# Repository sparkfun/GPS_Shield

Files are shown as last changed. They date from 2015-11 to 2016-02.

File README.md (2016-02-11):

SparkFun GPS Logger Shield
====================

SparkFun GPS Shield (https://www.sparkfun.com/products/13750)

[*SparkFun GPS Shield (GPS-13750)*](https://www.sparkfun.com/products/13750)

The [SparkFun GPS Logger Shield](https://www.sparkfun.com/products/13750) equips your Arduino with access to a GPS module, µSD memory card socket, and all of the other peripherals you'll need to turn your Arduino into a position-tracking, speed-monitoring, altitude-observing wonder logger. The shield is based around a [GP3906-TLP GPS Module](https://cdn.sparkfun.com/assets/learn_tutorials/4/6/8/GP3906-TLP_DataSheet_Rev_A01.pdf) -- a 66-channel GPS receiver featuring a MediaTek MT3339 architecture and an up to 10Hz update rate.

Repository Contents
-------------------

* **/Documentation** - Data sheets, additional product information 
* **/Firmware** - Example code 
* **/Hardware** - All Eagle design files (.brd, .sch)
* **/Production** - Production panel files (.brd)

Documentation
--------------
* **[Hookup Guide](https://learn.sparkfun.com/tutorials/gps-logger-shield-hookup-guide)** - Basic hookup guide for the SparkFun GPS Logger Shield.

Product Versions
----------------
* [GPS-13750](https://www.sparkfun.com/products/13750)- Initial release of the GPS Logger Shield

Version History
---------------
* [V_1.6](https://github.com/sparkfun/GPS_Shield/releases/tag/V_1.6) - Original GPS Shield - older GPS module, no µSD card support.

License Information
-------------------

This product is _**open source**_! 

Please review the LICENSE.md file for license information. 

If you have any questions or concerns on licensing, please contact techsupport@sparkfun.com.

Distributed as-is; no warranty is given.

- Your friends at SparkFun.

_<COLLABORATION CREDIT>_

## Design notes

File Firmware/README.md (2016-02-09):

SparkFun GPS Logger Shield Firmware
===================================

* **Examples** - Arduino examples
    * Basic_Passthrough_Software - GPS NMEA string passthough from GPS module to the Arduino serial monitor. Uses software serial on pins 8/9 to communicate with the GPS module, leaving the hardware UART on pins 0/1 free for serial monitoring. Good for an Arduino Uno, Pro, and RedBoard.
	* Basic_Passthrough_Hardware - GPS NMEA string passthough from GPS module to the Arduino serial monitor. Uses a hardware serial UART on pins 0/1 to communicate with the GPS module. Good for an Arduino Leonardo or Zero.
	* TinyGPSPlus_GPS_Shield - Uses the [TinyGPS++ Arduino Library](https://github.com/mikalhart/TinyGPSPlus/releases) to parse NMEA strings, and prints position, speed, time, date, and other information to the serial monitor.
	* CSV_Logger_TinyGPSPlus - Logs pertinent GPS data to a &micro;SD card. Uses the [TinyGPS++ Arduino Library](https://github.com/mikalhart/TinyGPSPlus/releases) to parse NMEA strings, and Arduino's built-in SD library to create and write to files on an SD card.

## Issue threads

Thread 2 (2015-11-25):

v20 Issues

ericorosel, 2015-11-25:
-Need PROD_ID for batt. clip (according to the BOM it is CONN-08044)

-This may not be an issue at all, but when I match up the Redboard ISP header and the GPS Shield ISP header they seem to be slightly off.

that's it!

ericorosel, 2015-11-25:
sorry, that's BATT-08044

jimblom, 2015-11-30:
Battery's all taken care of.

The ISP header may actually be slightly off position on the Redboard. The GPS shield matches up with an Arduino Uno and a SAMD21 Dev Breakout. Either way, with a little give in the headers it's close enough.

ericorosel, 2015-11-30:
Sounds good, thanks!

Closed 2015-11-30.

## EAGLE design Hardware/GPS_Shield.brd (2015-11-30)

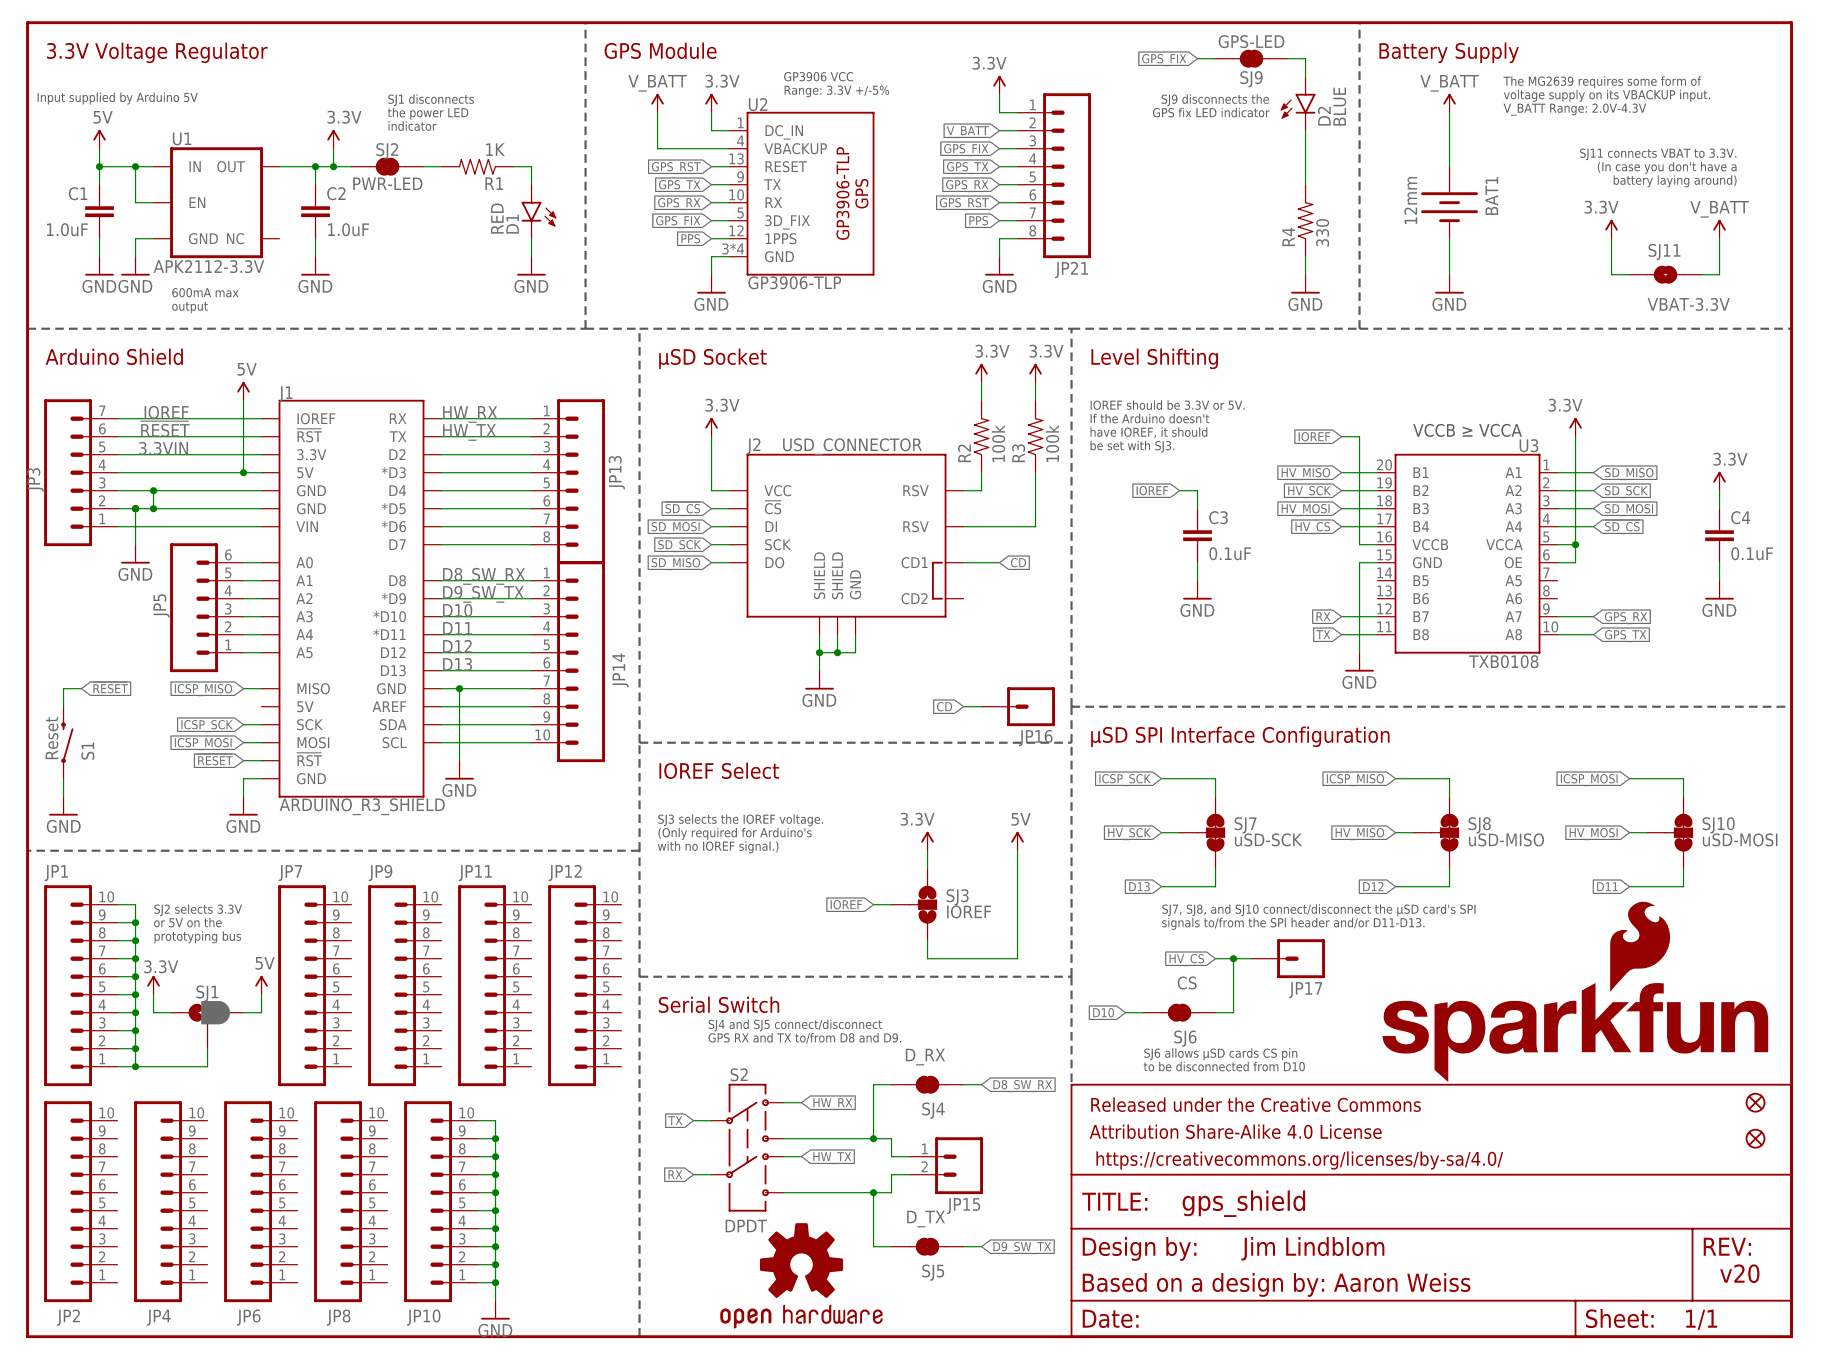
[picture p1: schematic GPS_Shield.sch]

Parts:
BAT1: 12mm; BATTCON_12MM
C1, C2: 1.0uF; 0603-CAP
C3, C4: 0.1uF; 0603-CAP
D1: RED; LED-0603
D2: BLUE; LED-0603
FRAME1: FRAME-LETTER; CREATIVE_COMMONS
J1: ARDUINO_R3_SHIELD; UNO_R3_SHIELD_ICSP_NOLABELS
J2: USD_CONNECTOR; MICRO-SD-SOCKET-PP
JP1, JP2, JP4, JP6, JP7, JP8, JP9, JP10, JP11, JP12, JP14: M10NO_SILK_PTH_FEMALE; 1X10_NO_SILK
JP3: M07NO_SILK; 1X07_NO_SILK
JP5: M06NO_SILK_FEMALE_PTH; 1X06_NO_SILK
JP13, JP21: M08NO_SILK_FEMALE_PTH; 1X08_NO_SILK
JP15: M021X02_NO_SILK; 1X02_NO_SILK
JP16, JP17: M01PTH_NO_SILK_YES_STOP; 1X01_NO_SILK
JP19, JP20: FIDUCIAL1X2; FIDUCIAL-1X2
LOGO1: OSHW-LOGOM; OSHW-LOGO-M
LOGO2: SFE_LOGO_NAME_FLAME.1_INCH; SFE_LOGO_NAME_FLAME_.1
R1: 1K; 0603-RES
R2, R3: 100k; 0603-RES
R4: 330; 0603-RES
S1: Reset; TACTILE-SWITCH-SMD
S2: DPDT; AYZ0202
SJ1: JUMPER-PAD-3-2OF3_NC_BY_PASTE; PAD-JUMPER-3-2OF3_NC_BY_PASTE_YES_SILK_FULL_BOX
SJ2: PWR-LED; PAD-JUMPER-2-NC_BY_TRACE_YES_SILK
SJ3: IOREF; PAD-JUMPER-3-NO_YES_SILK
SJ4: D_RX; PAD-JUMPER-2-NC_BY_TRACE_YES_SILK
SJ5: D_TX; PAD-JUMPER-2-NC_BY_TRACE_YES_SILK
SJ6: CS; PAD-JUMPER-2-NC_BY_TRACE_YES_SILK
SJ7: uSD-SCK; PAD-JUMPER-3-3OF3_NC_BY_TRACE_YES_SILK_FULL_BOX
SJ8: uSD-MISO; PAD-JUMPER-3-3OF3_NC_BY_TRACE_YES_SILK_FULL_BOX
SJ9: GPS-LED; PAD-JUMPER-2-NC_BY_TRACE_YES_SILK
SJ10: uSD-MOSI; PAD-JUMPER-3-3OF3_NC_BY_TRACE_YES_SILK_FULL_BOX
SJ11: VBAT-3.3V; PAD-JUMPER-2-NO_YES_SILK
U1: APK2112-3.3V; SOT23-5
U2: GP3906-TLP
U3: TXB0108; UFDFN-20

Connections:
3.3V: C2.1, C4.1, J2.VCC, JP21.1, R2.2, R3.2, SJ1.1, SJ2.1, SJ3.1, SJ11.1, U1.5 (OUT), U2.1 (DC_IN), U3.5 (VCCA), U3.6 (OE)
3.3VIN: J1.3.3V, JP3.5
5V: C1.1, J1.5V, JP3.4, SJ1.3, SJ3.3, U1.1 (IN), U1.3 (EN)
!RESET!: J1.RES (!RST!), J1.RST_ICSP (!RST!), JP3.6, S1.3 (2)
!SD_CS!: J2.CS (!CS), U3.4 (A4)
CD: J2.CD1, JP16.1
D8_SW_RX: J1.D8, JP14.1, SJ4.1
D9_SW_TX: J1.D9 (*D9), JP14.2, SJ5.1
D10: J1.D10 (*D10), JP14.3, SJ6.2
D11: J1.D11 (*D11), JP14.4, SJ10.3
D12: J1.D12, JP14.5, SJ8.3
D13: J1.D13, JP14.6, SJ7.3
GND: BAT1.GND (-), C1.2, C2.2, C3.2, C4.2, D1.C, J1.GND@0 (GND), J1.GND@1 (GND), J1.GND@2 (GND), J1.GND_ICSP (GND), J2.GND, J2.GND1 (SHIELD), J2.GND3 (SHIELD), JP3.2, JP3.3, JP10.1, JP10.2, JP10.3, JP10.4, JP10.5, JP10.6, JP10.7, JP10.8, JP10.9, JP10.10, JP14.7, JP21.8, R4.1, S1.1, U1.2 (GND), U2.3 (GND), U2.8 (GND), U2.11 (GND), U2.20 (GND), U3.15 (GND)
GPS_FIX: JP21.3, SJ9.2, U2.5 (3D_FIX)
GPS_RST: JP21.6, U2.13 (RESET)
GPS_RX: JP21.5, U2.10 (RX), U3.9 (A7)
GPS_TX: JP21.4, U2.9 (TX), U3.10 (A8)
HV_CS: JP17.1, SJ6.1, U3.17 (B4)
HV_MISO: SJ8.2, U3.20 (B1)
HV_MOSI: SJ10.2, U3.18 (B3)
HV_SCK: SJ7.2, U3.19 (B2)
HW_RX: J1.RX, JP13.1, S2.1
HW_TX: J1.TX, JP13.2, S2.4
ICSP_MISO: J1.MISO, SJ8.1
ICSP_MOSI: J1.MOSI, SJ10.1
ICSP_SCK: J1.SCK, SJ7.1
IOREF: C3.1, J1.IOREF, JP3.7, SJ3.2, U3.16 (VCCB)
unnamed: D1.A, R1.1
unnamed: D2.C, R4.2
unnamed: J1.A5, JP5.1
unnamed: J1.A4, JP5.2
unnamed: J1.D2, JP13.3
unnamed: J1.D3 (*D3), JP13.4
unnamed: J1.D4, JP13.5
unnamed: J1.D5 (*D5), JP13.6
unnamed: J1.D6 (*D6), JP13.7
unnamed: J1.D7, JP13.8
unnamed: J1.A3, JP5.3
unnamed: J1.A2, JP5.4
unnamed: J1.A1, JP5.5
unnamed: J1.A0, JP5.6
unnamed: R1.2, SJ2.2
unnamed: JP1.1, JP1.2, JP1.3, JP1.4, JP1.5, JP1.6, JP1.7, JP1.8, JP1.9, JP1.10, SJ1.2
unnamed: D2.A, SJ9.1
unnamed: J2.RSV1 (RSV), R2.1
unnamed: J2.RSV2 (RSV), R3.1
unnamed: J1.AREF, JP14.8
unnamed: J1.SDA, JP14.9
unnamed: J1.SCL, JP14.10
unnamed: J1.VIN, JP3.1
unnamed: JP15.2, S2.6, SJ5.2
unnamed: JP15.1, S2.3, SJ4.2
PPS: JP21.7, U2.12 (1PPS)
RX: S2.5, U3.12 (B7)
SD_MISO: J2.DO, U3.1 (A1)
SD_MOSI: J2.DI, U3.3 (A3)
SD_SCK: J2.SCLK (SCK), U3.2 (A2)
TX: S2.2, U3.11 (B8)
V_BATT: BAT1.PWR@1 (+), JP21.2, SJ11.2, U2.4 (VBACKUP)

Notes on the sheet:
GPS Module
Arduino Shield
Serial Switch
Jim Lindblom
v20
Based on a design by: Aaron Weiss
µSD Socket
Level Shifting
3.3V Voltage Regulator
µSD SPI Interface Configuration
IOREF Select
Input supplied by Arduino 5V
600mA max output
SJ1 disconnects the power LED indicator
SJ9 disconnects the GPS fix LED indicator
SJ2 selects 3.3V or 5V on the prototyping bus
VCCB ≥ VCCA
IOREF should be 3.3V or 5V. If the Arduino doesn't have IOREF, it should be set with SJ3.
SJ3 selects the IOREF voltage. (Only required for Arduino's with no IOREF signal.)
SJ7, SJ8, and SJ10 connect/disconnect the µSD card's SPI signals to/from the SPI header and/or D11-D13.
SJ6 allows µSD cards CS pin to be disconnected from D10
SJ4 and SJ5 connect/disconnect GPS RX and TX to/from D8 and D9.
GP3906 VCC Range: 3.3V +/-5%
SJ11 connects VBAT to 3.3V. (In case you don't have a battery laying around)
Battery Supply
The MG2639 requires some form of voltage supply on its VBACKUP input. V_BATT Range: 2.0V-4.3V

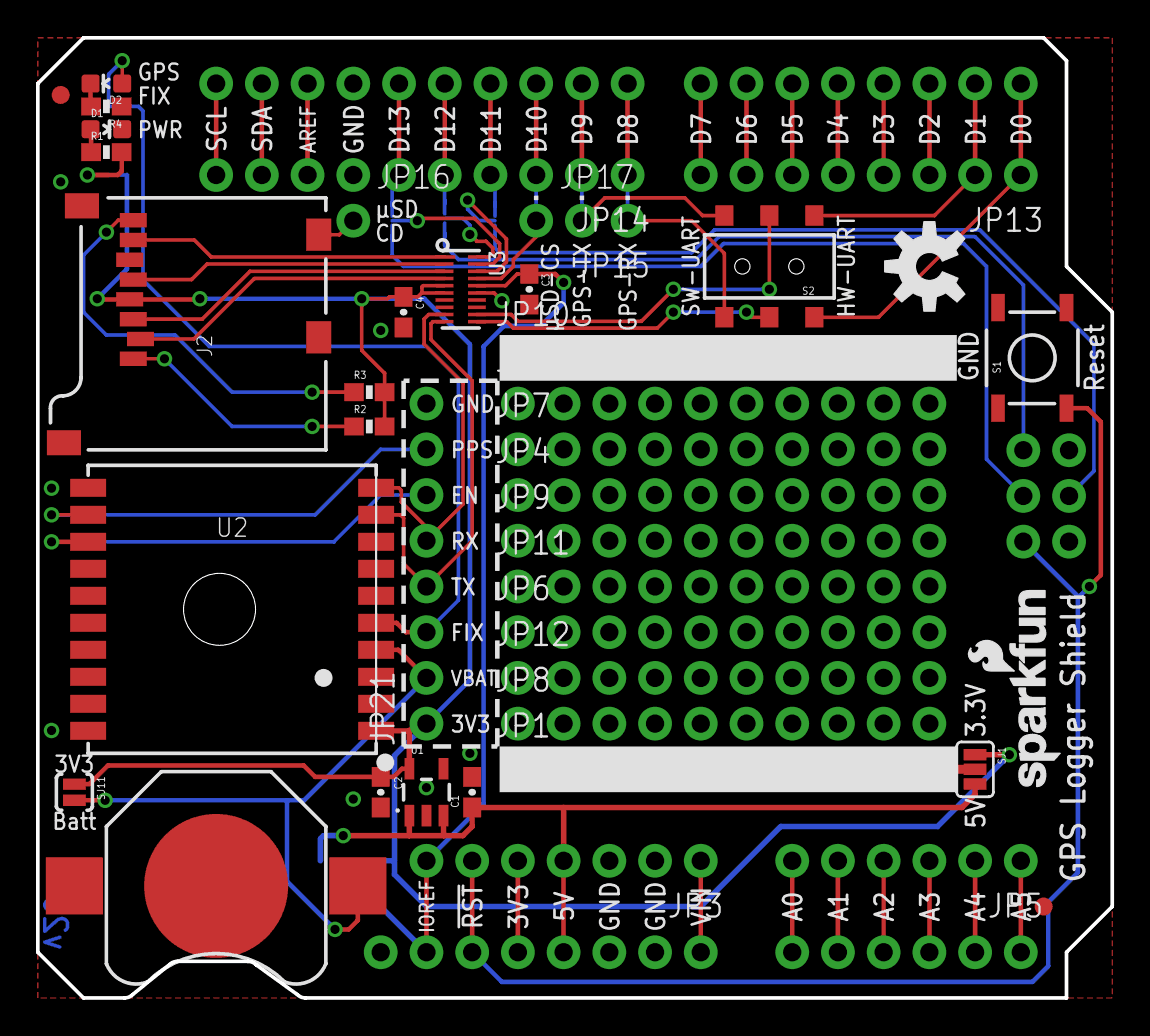
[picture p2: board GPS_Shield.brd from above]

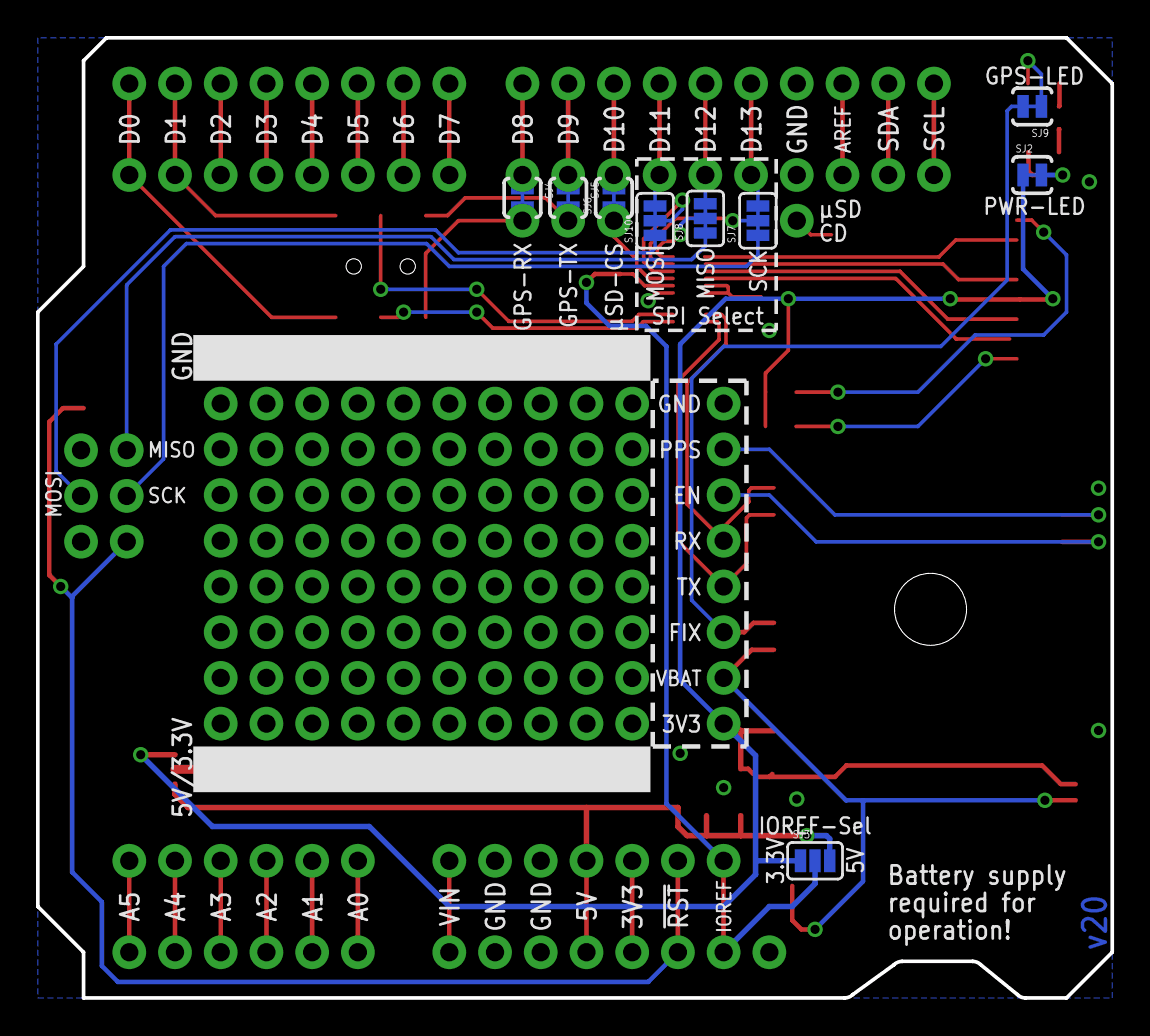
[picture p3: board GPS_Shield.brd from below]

Board: 2 copper layers, 59.7 x 53.3 mm, 52 parts (9 on the bottom side), 59 nets.

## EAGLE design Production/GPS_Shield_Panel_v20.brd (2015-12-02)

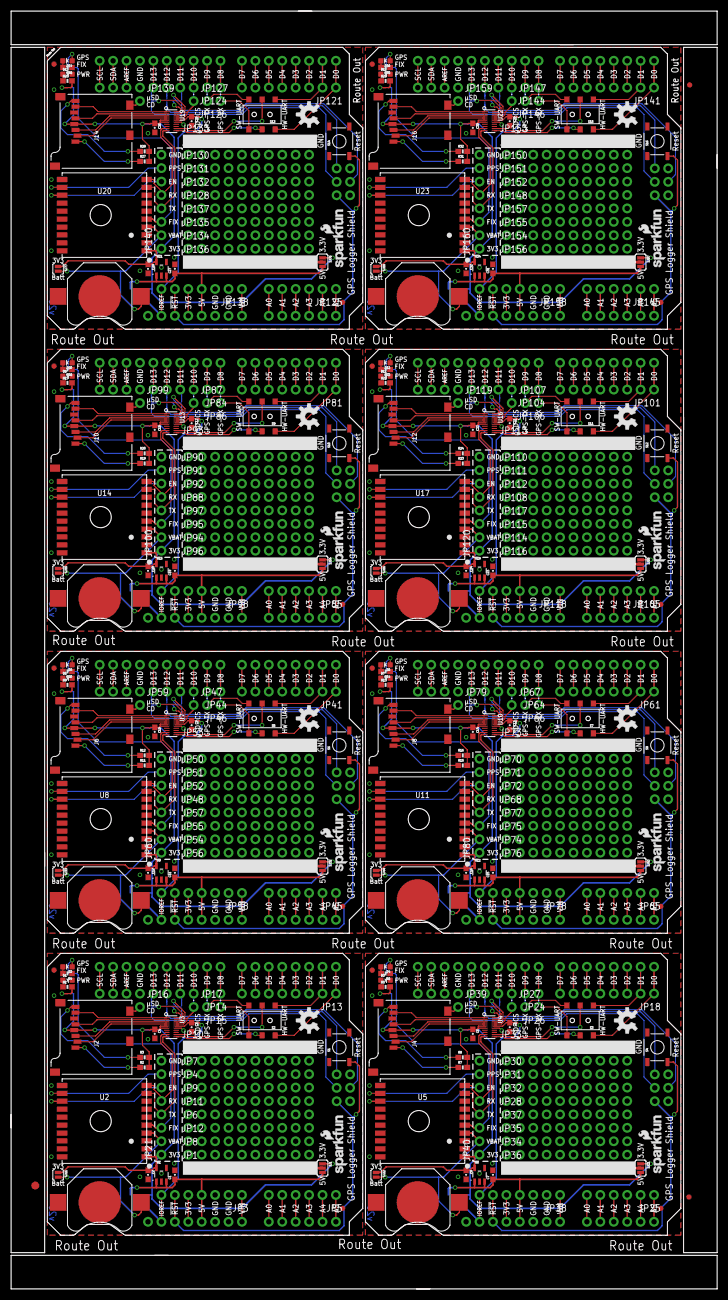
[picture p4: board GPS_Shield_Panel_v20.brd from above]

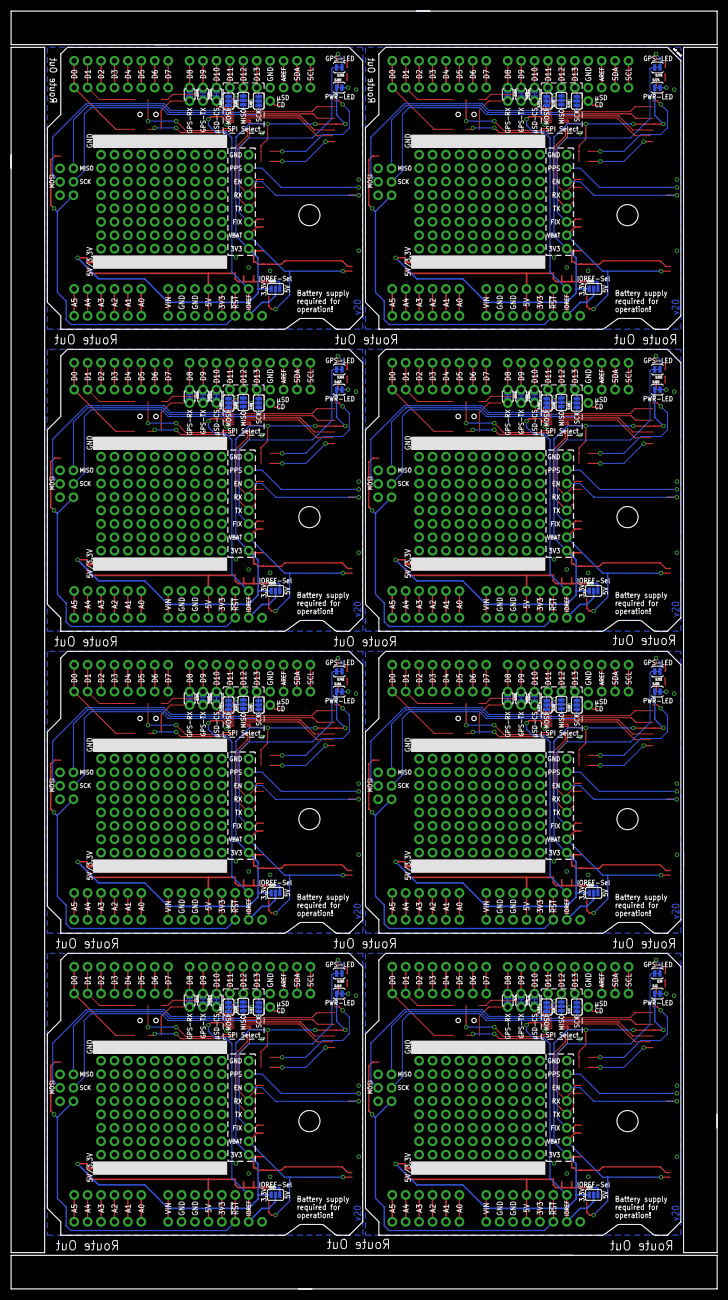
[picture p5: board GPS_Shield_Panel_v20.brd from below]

Board: 2 copper layers, 133.6 x 241.8 mm, 411 parts (72 on the bottom side), 472 nets.

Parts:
BAT1, BAT2, BAT3, BAT4, BAT5, BAT6, BAT7, BAT8: 12mm; BATTCON_12MM
C1, C2, C7, C8, C11, C12, C15, C16, C19, C20, C23, C24, C27, C28, C31, C32: 1.0uF; 0603-CAP
C3, C4, C5, C6, C9, C10, C13, C14, C17, C18, C21, C22, C25, C26, C29, C30: 0.1uF; 0603-CAP
D1, D3, D5, D7, D9, D11, D13, D15: RED; LED-0603
D2, D4, D6, D8, D10, D12, D14, D16: BLUE; LED-0603
E$1: FIDUCIAL-1.5X3
E$4, E$5: FIDUCIAL-1X2
J1, J3, J5, J7, J9, J11, J13, J15: ARDUINO_R3_SHIELD; UNO_R3_SHIELD_ICSP_NOLABELS
J2, J4, J6, J8, J10, J12, J14, J16: USD_CONNECTOR; MICRO-SD-SOCKET-PP
JP1, JP2, JP4, JP6, JP7, JP8, JP9, JP10, JP11, JP12, JP14, JP24, JP28, JP29, JP30, JP31, JP32, JP33, JP34, JP35, JP36, JP37, JP44, JP48, JP49, JP50, JP51, JP52, JP53, JP54, JP55, JP56, JP57, JP64, JP68, JP69, JP70, JP71, JP72, JP73, JP74, JP75, JP76, JP77, JP84, JP88, JP89, JP90, JP91, JP92, JP93, JP94, JP95, JP96, JP97, JP104, JP108, JP109, JP110, JP111, JP112, JP113, JP114, JP115, JP116, JP117, JP124, JP128, JP129, JP130, JP131, JP132, JP133, JP134, JP135, JP136, JP137, JP144, JP148, JP149, JP150, JP151, JP152, JP153, JP154, JP155, JP156, JP157: 1X10_NO_SILK
JP3, JP38, JP58, JP78, JP98, JP118, JP138, JP158: 1X07_NO_SILK
JP5, JP25, JP45, JP65, JP85, JP105, JP125, JP145: 1X06_NO_SILK
JP13, JP18, JP21, JP40, JP41, JP60, JP61, JP80, JP81, JP100, JP101, JP120, JP121, JP140, JP141, JP160: 1X08_NO_SILK
JP15, JP26, JP46, JP66, JP86, JP106, JP126, JP146: 1X02_NO_SILK
JP16, JP17, JP27, JP39, JP47, JP59, JP67, JP79, JP87, JP99, JP107, JP119, JP127, JP139, JP147, JP159: 1X01_NO_SILK
JP19, JP20, JP22, JP23, JP42, JP43, JP62, JP63, JP82, JP83, JP102, JP103, JP122, JP123, JP142, JP143: FIDUCIAL1X2; FIDUCIAL-1X2
LOGO1, LOGO4, LOGO6, LOGO8, LOGO10, LOGO12, LOGO14, LOGO16: OSHW-LOGOM; OSHW-LOGO-M
LOGO2, LOGO3, LOGO5, LOGO7, LOGO9, LOGO11, LOGO13, LOGO15: SFE_LOGO_NAME_FLAME.1_INCH; SFE_LOGO_NAME_FLAME_.1
R1, R5, R9, R13, R17, R21, R25, R29: 1K; 0603-RES
R2, R3, R7, R8, R11, R12, R15, R16, R19, R20, R23, R24, R27, R28, R31, R32: 100k; 0603-RES
R4, R6, R10, R14, R18, R22, R26, R30: 330; 0603-RES
S1, S4, S6, S8, S10, S12, S14, S16: Reset; TACTILE-SWITCH-SMD
S2, S3, S5, S7, S9, S11, S13, S15: DPDT; AYZ0202
SJ1, SJ21, SJ32, SJ43, SJ54, SJ65, SJ76, SJ87: PAD-JUMPER-3-2OF3_NC_BY_PASTE_YES_SILK_FULL_BOX
SJ2, SJ19, SJ30, SJ41, SJ52, SJ63, SJ74, SJ85: PWR-LED; PAD-JUMPER-2-NC_BY_TRACE_YES_SILK
SJ3, SJ14, SJ25, SJ36, SJ47, SJ58, SJ69, SJ80: IOREF; PAD-JUMPER-3-NO_YES_SILK
SJ4, SJ12, SJ23, SJ34, SJ45, SJ56, SJ67, SJ78: D_RX; PAD-JUMPER-2-NC_BY_TRACE_YES_SILK
SJ5, SJ13, SJ24, SJ35, SJ46, SJ57, SJ68, SJ79: D_TX; PAD-JUMPER-2-NC_BY_TRACE_YES_SILK
SJ6, SJ18, SJ29, SJ40, SJ51, SJ62, SJ73, SJ84: CS; PAD-JUMPER-2-NC_BY_TRACE_YES_SILK
SJ7, SJ17, SJ28, SJ39, SJ50, SJ61, SJ72, SJ83: uSD-SCK; PAD-JUMPER-3-3OF3_NC_BY_TRACE_YES_SILK_FULL_BOX
SJ8, SJ15, SJ26, SJ37, SJ48, SJ59, SJ70, SJ81: uSD-MISO; PAD-JUMPER-3-3OF3_NC_BY_TRACE_YES_SILK_FULL_BOX
SJ9, SJ20, SJ31, SJ42, SJ53, SJ64, SJ75, SJ86: GPS-LED; PAD-JUMPER-2-NC_BY_TRACE_YES_SILK
SJ10, SJ16, SJ27, SJ38, SJ49, SJ60, SJ71, SJ82: uSD-MOSI; PAD-JUMPER-3-3OF3_NC_BY_TRACE_YES_SILK_FULL_BOX
SJ11, SJ22, SJ33, SJ44, SJ55, SJ66, SJ77, SJ88: VBAT-3.3V; PAD-JUMPER-2-NO_YES_SILK
U1, U6, U9, U12, U15, U18, U21, U24: APK2112-3.3V; SOT23-5
U2, U5, U8, U11, U14, U17, U20, U23: GP3906-TLP
U3, U4, U7, U10, U13, U16, U19, U22: TXB0108; UFDFN-20

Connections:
3.3V: C2.1, C4.1, J2.VCC, JP21.1, R2.2, R3.2, SJ1.1, SJ2.1, SJ3.1, SJ11.1, U1.5, U2.1, U3.5, U3.6
3.3V1: C6.1, C8.1, J4.VCC, JP40.1, R7.2, R8.2, SJ14.1, SJ19.1, SJ21.1, SJ22.1, U4.5, U4.6, U5.1, U6.5
3.3V2: C10.1, C12.1, J6.VCC, JP60.1, R11.2, R12.2, SJ25.1, SJ30.1, SJ32.1, SJ33.1, U7.5, U7.6, U8.1, U9.5
3.3V3: C14.1, C16.1, J8.VCC, JP80.1, R15.2, R16.2, SJ36.1, SJ41.1, SJ43.1, SJ44.1, U10.5, U10.6, U11.1, U12.5
3.3V4: C18.1, C20.1, J10.VCC, JP100.1, R19.2, R20.2, SJ47.1, SJ52.1, SJ54.1, SJ55.1, U13.5, U13.6, U14.1, U15.5
3.3V5: C22.1, C24.1, J12.VCC, JP120.1, R23.2, R24.2, SJ58.1, SJ63.1, SJ65.1, SJ66.1, U16.5, U16.6, U17.1, U18.5
3.3V6: C26.1, C28.1, J14.VCC, JP140.1, R27.2, R28.2, SJ69.1, SJ74.1, SJ76.1, SJ77.1, U19.5, U19.6, U20.1, U21.5
3.3V7: C30.1, C32.1, J16.VCC, JP160.1, R31.2, R32.2, SJ80.1, SJ85.1, SJ87.1, SJ88.1, U22.5, U22.6, U23.1, U24.5
3.3VIN: J1.3.3V, JP3.5
3.3VIN1: J3.3.3V, JP38.5
3.3VIN2: J5.3.3V, JP58.5
3.3VIN3: J7.3.3V, JP78.5
3.3VIN4: J9.3.3V, JP98.5
3.3VIN5: J11.3.3V, JP118.5
3.3VIN6: J13.3.3V, JP138.5
3.3VIN7: J15.3.3V, JP158.5
5V: C1.1, J1.5V, JP3.4, SJ1.3, SJ3.3, U1.1, U1.3
5V1: C7.1, J3.5V, JP38.4, SJ14.3, SJ21.3, U6.1, U6.3
5V2: C11.1, J5.5V, JP58.4, SJ25.3, SJ32.3, U9.1, U9.3
5V3: C15.1, J7.5V, JP78.4, SJ36.3, SJ43.3, U12.1, U12.3
5V4: C19.1, J9.5V, JP98.4, SJ47.3, SJ54.3, U15.1, U15.3
5V5: C23.1, J11.5V, JP118.4, SJ58.3, SJ65.3, U18.1, U18.3
5V6: C27.1, J13.5V, JP138.4, SJ69.3, SJ76.3, U21.1, U21.3
5V7: C31.1, J15.5V, JP158.4, SJ80.3, SJ87.3, U24.1, U24.3
!RESET!: J1.RES, J1.RST_ICSP, JP3.6, S1.3
!RESET!1: J3.RES, J3.RST_ICSP, JP38.6, S4.3
!RESET!2: J5.RES, J5.RST_ICSP, JP58.6, S6.3
!RESET!3: J7.RES, J7.RST_ICSP, JP78.6, S8.3
!RESET!4: J9.RES, J9.RST_ICSP, JP98.6, S10.3
!RESET!5: J11.RES, J11.RST_ICSP, JP118.6, S12.3
!RESET!6: J13.RES, J13.RST_ICSP, JP138.6, S14.3
!RESET!7: J15.RES, J15.RST_ICSP, JP158.6, S16.3
!SD_CS!: J2.CS, U3.4
!SD_CS!1: J4.CS, U4.4
!SD_CS!2: J6.CS, U7.4
!SD_CS!3: J8.CS, U10.4
!SD_CS!4: J10.CS, U13.4
!SD_CS!5: J12.CS, U16.4
!SD_CS!6: J14.CS, U19.4
!SD_CS!7: J16.CS, U22.4
CD: J2.CD1, JP16.1
CD1: J4.CD1, JP39.1
CD2: J6.CD1, JP59.1
CD3: J8.CD1, JP79.1
CD4: J10.CD1, JP99.1
CD5: J12.CD1, JP119.1
CD6: J14.CD1, JP139.1
CD7: J16.CD1, JP159.1
D1: J3.D10, JP24.3, SJ18.2
D2: J3.D11, JP24.4, SJ16.3
D3: J3.D12, JP24.5, SJ15.3
D4: J3.D13, JP24.6, SJ17.3
D5: J5.D10, JP44.3, SJ29.2
D6: J5.D11, JP44.4, SJ27.3
D7: J5.D12, JP44.5, SJ26.3
D8: J5.D13, JP44.6, SJ28.3
D8_SW_RX: J1.D8, JP14.1, SJ4.1
D8_SW_RX1: J3.D8, JP24.1, SJ12.1
D8_SW_RX2: J5.D8, JP44.1, SJ23.1
D8_SW_RX3: J7.D8, JP64.1, SJ34.1
D8_SW_RX4: J9.D8, JP84.1, SJ45.1
D8_SW_RX5: J11.D8, JP104.1, SJ56.1
D8_SW_RX6: J13.D8, JP124.1, SJ67.1
D8_SW_RX7: J15.D8, JP144.1, SJ78.1
D9: J7.D10, JP64.3, SJ40.2
D9_SW_TX: J1.D9, JP14.2, SJ5.1
D9_SW_TX1: J3.D9, JP24.2, SJ13.1
D9_SW_TX2: J5.D9, JP44.2, SJ24.1
D9_SW_TX3: J7.D9, JP64.2, SJ35.1
D9_SW_TX4: J9.D9, JP84.2, SJ46.1
D9_SW_TX5: J11.D9, JP104.2, SJ57.1
D9_SW_TX6: J13.D9, JP124.2, SJ68.1
D9_SW_TX7: J15.D9, JP144.2, SJ79.1
D10: J1.D10, JP14.3, SJ6.2
D11: J1.D11, JP14.4, SJ10.3
D12: J1.D12, JP14.5, SJ8.3
D13: J1.D13, JP14.6, SJ7.3
D14: J7.D11, JP64.4, SJ38.3
D15: J7.D12, JP64.5, SJ37.3
D16: J7.D13, JP64.6, SJ39.3
D17: J9.D10, JP84.3, SJ51.2
D18: J9.D11, JP84.4, SJ49.3
D19: J9.D12, JP84.5, SJ48.3
D20: J9.D13, JP84.6, SJ50.3
D21: J11.D10, JP104.3, SJ62.2
D22: J11.D11, JP104.4, SJ60.3
D23: J11.D12, JP104.5, SJ59.3
D24: J11.D13, JP104.6, SJ61.3
D25: J13.D10, JP124.3, SJ73.2
D26: J13.D11, JP124.4, SJ71.3
D27: J13.D12, JP124.5, SJ70.3
D28: J13.D13, JP124.6, SJ72.3
D29: J15.D10, JP144.3, SJ84.2
D30: J15.D11, JP144.4, SJ82.3
D31: J15.D12, JP144.5, SJ81.3
D32: J15.D13, JP144.6, SJ83.3
GND: BAT1.GND, C1.2, C2.2, C3.2, C4.2, D1.C, J1.GND@0, J1.GND@1, J1.GND@2, J1.GND_ICSP, J2.GND, J2.GND1, J2.GND3, JP3.2, JP3.3, JP10.1, JP10.2, JP10.3, JP10.4, JP10.5, JP10.6, JP10.7, JP10.8, JP10.9, JP10.10, JP14.7, JP21.8, R4.1, S1.1, U1.2, U2.3, U2.8, U2.11, U2.20, U3.15
GND1: BAT2.GND, C5.2, C6.2, C7.2, C8.2, D3.C, J3.GND@0, J3.GND@1, J3.GND@2, J3.GND_ICSP, J4.GND, J4.GND1, J4.GND3, JP24.7, JP33.1, JP33.2, JP33.3, JP33.4, JP33.5, JP33.6, JP33.7, JP33.8, JP33.9, JP33.10, JP38.2, JP38.3, JP40.8, R6.1, S4.1, U4.15, U5.3, U5.8, U5.11, U5.20, U6.2
GND2: BAT3.GND, C9.2, C10.2, C11.2, C12.2, D5.C, J5.GND@0, J5.GND@1, J5.GND@2, J5.GND_ICSP, J6.GND, J6.GND1, J6.GND3, JP44.7, JP53.1, JP53.2, JP53.3, JP53.4, JP53.5, JP53.6, JP53.7, JP53.8, JP53.9, JP53.10, JP58.2, JP58.3, JP60.8, R10.1, S6.1, U7.15, U8.3, U8.8, U8.11, U8.20, U9.2
GND3: BAT4.GND, C13.2, C14.2, C15.2, C16.2, D7.C, J7.GND@0, J7.GND@1, J7.GND@2, J7.GND_ICSP, J8.GND, J8.GND1, J8.GND3, JP64.7, JP73.1, JP73.2, JP73.3, JP73.4, JP73.5, JP73.6, JP73.7, JP73.8, JP73.9, JP73.10, JP78.2, JP78.3, JP80.8, R14.1, S8.1, U10.15, U11.3, U11.8, U11.11, U11.20, U12.2
GND4: BAT5.GND, C17.2, C18.2, C19.2, C20.2, D9.C, J9.GND@0, J9.GND@1, J9.GND@2, J9.GND_ICSP, J10.GND, J10.GND1, J10.GND3, JP84.7, JP93.1, JP93.2, JP93.3, JP93.4, JP93.5, JP93.6, JP93.7, JP93.8, JP93.9, JP93.10, JP98.2, JP98.3, JP100.8, R18.1, S10.1, U13.15, U14.3, U14.8, U14.11, U14.20, U15.2
GND5: BAT6.GND, C21.2, C22.2, C23.2, C24.2, D11.C, J11.GND@0, J11.GND@1, J11.GND@2, J11.GND_ICSP, J12.GND, J12.GND1, J12.GND3, JP104.7, JP113.1, JP113.2, JP113.3, JP113.4, JP113.5, JP113.6, JP113.7, JP113.8, JP113.9, JP113.10, JP118.2, JP118.3, JP120.8, R22.1, S12.1, U16.15, U17.3, U17.8, U17.11, U17.20, U18.2
GND6: BAT7.GND, C25.2, C26.2, C27.2, C28.2, D13.C, J13.GND@0, J13.GND@1, J13.GND@2, J13.GND_ICSP, J14.GND, J14.GND1, J14.GND3, JP124.7, JP133.1, JP133.2, JP133.3, JP133.4, JP133.5, JP133.6, JP133.7, JP133.8, JP133.9, JP133.10, JP138.2, JP138.3, JP140.8, R26.1, S14.1, U19.15, U20.3, U20.8, U20.11, U20.20, U21.2
GND7: BAT8.GND, C29.2, C30.2, C31.2, C32.2, D15.C, J15.GND@0, J15.GND@1, J15.GND@2, J15.GND_ICSP, J16.GND, J16.GND1, J16.GND3, JP144.7, JP153.1, JP153.2, JP153.3, JP153.4, JP153.5, JP153.6, JP153.7, JP153.8, JP153.9, JP153.10, JP158.2, JP158.3, JP160.8, R30.1, S16.1, U22.15, U23.3, U23.8, U23.11, U23.20, U24.2
GPS_FIX: JP21.3, SJ9.2, U2.5
GPS_FIX1: JP40.3, SJ20.2, U5.5
GPS_FIX2: JP60.3, SJ31.2, U8.5
GPS_FIX3: JP80.3, SJ42.2, U11.5
GPS_FIX4: JP100.3, SJ53.2, U14.5
GPS_FIX5: JP120.3, SJ64.2, U17.5
GPS_FIX6: JP140.3, SJ75.2, U20.5
GPS_FIX7: JP160.3, SJ86.2, U23.5
GPS_RST: JP21.6, U2.13
GPS_RST1: JP40.6, U5.13
GPS_RST2: JP60.6, U8.13
GPS_RST3: JP80.6, U11.13
GPS_RST4: JP100.6, U14.13
GPS_RST5: JP120.6, U17.13
GPS_RST6: JP140.6, U20.13
GPS_RST7: JP160.6, U23.13
GPS_RX: JP21.5, U2.10, U3.9
GPS_RX1: JP40.5, U4.9, U5.10
GPS_RX2: JP60.5, U7.9, U8.10
GPS_RX3: JP80.5, U10.9, U11.10
GPS_RX4: JP100.5, U13.9, U14.10
GPS_RX5: JP120.5, U16.9, U17.10
GPS_RX6: JP140.5, U19.9, U20.10
GPS_RX7: JP160.5, U22.9, U23.10
GPS_TX: JP21.4, U2.9, U3.10
GPS_TX1: JP40.4, U4.10, U5.9
GPS_TX2: JP60.4, U7.10, U8.9
GPS_TX3: JP80.4, U10.10, U11.9
GPS_TX4: JP100.4, U13.10, U14.9
GPS_TX5: JP120.4, U16.10, U17.9
GPS_TX6: JP140.4, U19.10, U20.9
GPS_TX7: JP160.4, U22.10, U23.9
HV_CS: JP17.1, SJ6.1, U3.17
HV_CS1: JP27.1, SJ18.1, U4.17
HV_CS2: JP47.1, SJ29.1, U7.17
HV_CS3: JP67.1, SJ40.1, U10.17
HV_CS4: JP87.1, SJ51.1, U13.17
HV_CS5: JP107.1, SJ62.1, U16.17
HV_CS6: JP127.1, SJ73.1, U19.17
HV_CS7: JP147.1, SJ84.1, U22.17
HV_MISO: SJ8.2, U3.20
HV_MISO1: SJ15.2, U4.20
HV_MISO2: SJ26.2, U7.20
HV_MISO3: SJ37.2, U10.20
HV_MISO4: SJ48.2, U13.20
HV_MISO5: SJ59.2, U16.20
HV_MISO6: SJ70.2, U19.20
HV_MISO7: SJ81.2, U22.20
HV_MOSI: SJ10.2, U3.18
HV_MOSI1: SJ16.2, U4.18
HV_MOSI2: SJ27.2, U7.18
HV_MOSI3: SJ38.2, U10.18
HV_MOSI4: SJ49.2, U13.18
HV_MOSI5: SJ60.2, U16.18
HV_MOSI6: SJ71.2, U19.18
HV_MOSI7: SJ82.2, U22.18
HV_SCK: SJ7.2, U3.19
HV_SCK1: SJ17.2, U4.19
HV_SCK2: SJ28.2, U7.19
HV_SCK3: SJ39.2, U10.19
HV_SCK4: SJ50.2, U13.19
HV_SCK5: SJ61.2, U16.19
HV_SCK6: SJ72.2, U19.19
HV_SCK7: SJ83.2, U22.19
HW_RX: J1.RX, JP13.1, S2.1
HW_RX1: J3.RX, JP18.1, S3.1
HW_RX2: J5.RX, JP41.1, S5.1
HW_RX3: J7.RX, JP61.1, S7.1
HW_RX4: J9.RX, JP81.1, S9.1
HW_RX5: J11.RX, JP101.1, S11.1
HW_RX6: J13.RX, JP121.1, S13.1
HW_RX7: J15.RX, JP141.1, S15.1
HW_TX: J1.TX, JP13.2, S2.4
HW_TX1: J3.TX, JP18.2, S3.4
HW_TX2: J5.TX, JP41.2, S5.4
HW_TX3: J7.TX, JP61.2, S7.4
HW_TX4: J9.TX, JP81.2, S9.4
HW_TX5: J11.TX, JP101.2, S11.4
HW_TX6: J13.TX, JP121.2, S13.4
HW_TX7: J15.TX, JP141.2, S15.4
ICSP_MISO: J1.MISO, SJ8.1
ICSP_MISO1: J3.MISO, SJ15.1
ICSP_MISO2: J5.MISO, SJ26.1
ICSP_MISO3: J7.MISO, SJ37.1
ICSP_MISO4: J9.MISO, SJ48.1
ICSP_MISO5: J11.MISO, SJ59.1
ICSP_MISO6: J13.MISO, SJ70.1
ICSP_MISO7: J15.MISO, SJ81.1
ICSP_MOSI: J1.MOSI, SJ10.1
ICSP_MOSI1: J3.MOSI, SJ16.1
ICSP_MOSI2: J5.MOSI, SJ27.1
ICSP_MOSI3: J7.MOSI, SJ38.1
ICSP_MOSI4: J9.MOSI, SJ49.1
ICSP_MOSI5: J11.MOSI, SJ60.1
ICSP_MOSI6: J13.MOSI, SJ71.1
ICSP_MOSI7: J15.MOSI, SJ82.1
ICSP_SCK: J1.SCK, SJ7.1
ICSP_SCK1: J3.SCK, SJ17.1
ICSP_SCK2: J5.SCK, SJ28.1
ICSP_SCK3: J7.SCK, SJ39.1
ICSP_SCK4: J9.SCK, SJ50.1
ICSP_SCK5: J11.SCK, SJ61.1
ICSP_SCK6: J13.SCK, SJ72.1
ICSP_SCK7: J15.SCK, SJ83.1
IOREF: C3.1, J1.IOREF, JP3.7, SJ3.2, U3.16
IOREF1: C5.1, J3.IOREF, JP38.7, SJ14.2, U4.16
IOREF2: C9.1, J5.IOREF, JP58.7, SJ25.2, U7.16
IOREF3: C13.1, J7.IOREF, JP78.7, SJ36.2, U10.16
IOREF4: C17.1, J9.IOREF, JP98.7, SJ47.2, U13.16
IOREF5: C21.1, J11.IOREF, JP118.7, SJ58.2, U16.16
IOREF6: C25.1, J13.IOREF, JP138.7, SJ69.2, U19.16
IOREF7: C29.1, J15.IOREF, JP158.7, SJ80.2, U22.16
unnamed: D1.A, R1.1
unnamed: D2.C, R4.2
unnamed: J1.A5, JP5.1
unnamed: J1.A4, JP5.2
unnamed: J1.D2, JP13.3
unnamed: J1.D3, JP13.4
unnamed: J1.D4, JP13.5
unnamed: J1.D5, JP13.6
unnamed: J1.D6, JP13.7
unnamed: J1.D7, JP13.8
unnamed: J1.A3, JP5.3
unnamed: J1.A2, JP5.4
unnamed: J1.A1, JP5.5
unnamed: J1.A0, JP5.6
unnamed: R1.2, SJ2.2
unnamed: JP1.1, JP1.2, JP1.3, JP1.4, JP1.5, JP1.6, JP1.7, JP1.8, JP1.9, JP1.10, SJ1.2
unnamed: D2.A, SJ9.1
unnamed: J2.RSV1, R2.1
unnamed: J2.RSV2, R3.1
unnamed: J1.AREF, JP14.8
unnamed: J1.SDA, JP14.9
unnamed: J1.SCL, JP14.10
unnamed: D3.A, R5.1
unnamed: J1.VIN, JP3.1
unnamed: JP26.2, S3.6, SJ13.2
unnamed: JP26.1, S3.3, SJ12.2
unnamed: J3.D2, JP18.3
unnamed: J3.D3, JP18.4
unnamed: J3.D4, JP18.5
unnamed: J3.D5, JP18.6
unnamed: J3.D6, JP18.7
unnamed: J3.D7, JP18.8
unnamed: J3.AREF, JP24.8
unnamed: J3.SDA, JP24.9
unnamed: J3.SCL, JP24.10
unnamed: J3.VIN, JP38.1
unnamed: J3.A5, JP25.1
unnamed: J3.A4, JP25.2
unnamed: J3.A3, JP25.3
unnamed: J3.A2, JP25.4
unnamed: J3.A1, JP25.5
unnamed: J3.A0, JP25.6
unnamed: R5.2, SJ19.2
unnamed: D4.C, R6.2
unnamed: D4.A, SJ20.1
unnamed: JP36.1, JP36.2, JP36.3, JP36.4, JP36.5, JP36.6, JP36.7, JP36.8, JP36.9, JP36.10, SJ21.2
unnamed: J4.RSV1, R7.1
unnamed: J4.RSV2, R8.1
unnamed: D5.A, R9.1
unnamed: JP46.2, S5.6, SJ24.2
unnamed: JP46.1, S5.3, SJ23.2
unnamed: J5.D2, JP41.3
unnamed: J5.D3, JP41.4
unnamed: J5.D4, JP41.5
unnamed: J5.D5, JP41.6
unnamed: J5.D6, JP41.7
unnamed: J5.D7, JP41.8
unnamed: J5.AREF, JP44.8
unnamed: J5.SDA, JP44.9
unnamed: J5.SCL, JP44.10
unnamed: J5.VIN, JP58.1
unnamed: J5.A5, JP45.1
unnamed: J5.A4, JP45.2
unnamed: J5.A3, JP45.3
unnamed: J5.A2, JP45.4
unnamed: J5.A1, JP45.5
unnamed: J5.A0, JP45.6
unnamed: R9.2, SJ30.2
unnamed: D6.C, R10.2
unnamed: D6.A, SJ31.1
unnamed: JP56.1, JP56.2, JP56.3, JP56.4, JP56.5, JP56.6, JP56.7, JP56.8, JP56.9, JP56.10, SJ32.2
unnamed: J6.RSV1, R11.1
unnamed: J6.RSV2, R12.1
unnamed: D7.A, R13.1
unnamed: JP66.2, S7.6, SJ35.2
unnamed: JP66.1, S7.3, SJ34.2
unnamed: J7.D2, JP61.3
unnamed: J7.D3, JP61.4
unnamed: J7.D4, JP61.5
unnamed: J7.D5, JP61.6
unnamed: J7.D6, JP61.7
unnamed: J7.D7, JP61.8
unnamed: J7.AREF, JP64.8
unnamed: J7.SDA, JP64.9
unnamed: J7.SCL, JP64.10
unnamed: J7.VIN, JP78.1
unnamed: J7.A5, JP65.1
unnamed: J7.A4, JP65.2
unnamed: J7.A3, JP65.3
unnamed: J7.A2, JP65.4
unnamed: J7.A1, JP65.5
unnamed: J7.A0, JP65.6
unnamed: R13.2, SJ41.2
unnamed: D8.C, R14.2
unnamed: D8.A, SJ42.1
unnamed: JP76.1, JP76.2, JP76.3, JP76.4, JP76.5, JP76.6, JP76.7, JP76.8, JP76.9, JP76.10, SJ43.2
unnamed: J8.RSV1, R15.1
unnamed: J8.RSV2, R16.1
unnamed: D9.A, R17.1
unnamed: JP86.2, S9.6, SJ46.2
unnamed: JP86.1, S9.3, SJ45.2
unnamed: J9.D2, JP81.3
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

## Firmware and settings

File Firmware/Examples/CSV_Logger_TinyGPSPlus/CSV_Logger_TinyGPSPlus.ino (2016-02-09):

/******************************************************************************
  CSV_Logger_TinyGPSPlus.ino
  Log GPS data to a CSV file on a uSD card
  By Jim Lindblom @ SparkFun Electronics
  February 9, 2016
  https://github.com/sparkfun/GPS_Shield

  This example uses SoftwareSerial to communicate with the GPS module on
  pins 8 and 9, then communicates over SPI to log that data to a uSD card.

  It uses the TinyGPS++ library to parse the NMEA strings sent by the GPS module,
  and prints interesting GPS information - comma separated - to a newly created
  file on the SD card.

  Resources:
  TinyGPS++ Library  - https://github.com/mikalhart/TinyGPSPlus/releases
  SD Library (Built-in)
  SoftwareSerial Library (Built-in)

  Development/hardware environment specifics:
  Arduino IDE 1.6.7
  GPS Logger Shield v2.0 - Make sure the UART switch is set to SW-UART
  Arduino Uno, RedBoard, Pro, Mega, etc.
******************************************************************************/

#include <SPI.h>
#include <SD.h>
#include <TinyGPS++.h>

#define ARDUINO_USD_CS 10 // uSD card CS pin (pin 10 on SparkFun GPS Logger Shield)

/////////////////////////
// Log File Defintions //
/////////////////////////
// Keep in mind, the SD library has max file name lengths of 8.3 - 8 char prefix,
// and a 3 char suffix.
// Our log files are called "gpslogXX.csv, so "gpslog99.csv" is our max file.
#define LOG_FILE_PREFIX "gpslog" // Name of the log file.
#define MAX_LOG_FILES 100 // Number of log files that can be made
#define LOG_FILE_SUFFIX "csv" // Suffix of the log file
char logFileName[13]; // Char string to store the log file name
// Data to be logged:
#define LOG_COLUMN_COUNT 8
char * log_col_names[LOG_COLUMN_COUNT] = {
  "longitude", "latitude", "altitude", "speed", "course", "date", "time", "satellites"
}; // log_col_names is printed at the top of the file.

//////////////////////
// Log Rate Control //
//////////////////////
#define LOG_RATE 5000 // Log every 5 seconds
unsigned long lastLog = 0; // Global var to keep of last time we logged

/////////////////////////
// TinyGPS Definitions //
/////////////////////////
TinyGPSPlus tinyGPS; // tinyGPSPlus object to be used throughout
#define GPS_BAUD 9600 // GPS module's default baud rate

/////////////////////////////////
// GPS Serial Port Definitions //
/////////////////////////////////
// If you're using an Arduino Uno, Mega, RedBoard, or any board that uses the
// 0/1 UART for programming/Serial monitor-ing, use SoftwareSerial:
#include <SoftwareSerial.h>
#define ARDUINO_GPS_RX 9 // GPS TX, Arduino RX pin
#define ARDUINO_GPS_TX 8 // GPS RX, Arduino TX pin
SoftwareSerial ssGPS(ARDUINO_GPS_TX, ARDUINO_GPS_RX); // Create a SoftwareSerial

// Set gpsPort to either ssGPS if using SoftwareSerial or Serial1 if using an
// Arduino with a dedicated hardware serial port
#define gpsPort ssGPS  // Alternatively, use Serial1 on the Leonardo

// Define the serial monitor port. On the Uno, Mega, and Leonardo this is 'Serial'
//  on other boards this may be 'SerialUSB'
#define SerialMonitor Serial

void setup()
{
  SerialMonitor.begin(9600);
  gpsPort.begin(GPS_BAUD);

  SerialMonitor.println("Setting up SD card.");
  // see if the card is present and can be initialized:
  if (!SD.begin(ARDUINO_USD_CS))
  {
    SerialMonitor.println("Error initializing SD card.");
  }
  updateFileName(); // Each time we start, create a new file, increment the number
  printHeader(); // Print a header at the top of the new file
}

void loop()
{
  if ((lastLog + LOG_RATE) <= millis())
  { // If it's been LOG_RATE milliseconds since the last log:
    if (tinyGPS.location.isUpdated()) // If the GPS data is vaild
    {
      if (logGPSData()) // Log the GPS data
      {
        SerialMonitor.println("GPS logged."); // Print a debug message
        lastLog = millis(); // Update the lastLog variable
      }
      else // If we failed to log GPS
      { // Print an error, don't update lastLog
        SerialMonitor.println("Failed to log new GPS data.");
      }
    }
    else // If GPS data isn't valid
    {
      // Print a debug message. Maybe we don't have enough satellites yet.
      SerialMonitor.print("No GPS data. Sats: ");
      SerialMonitor.println(tinyGPS.satellites.value());
    }
  }

  // If we're not logging, continue to "feed" the tinyGPS object:
  while (gpsPort.available())
    tinyGPS.encode(gpsPort.read());
}

byte logGPSData()
{
  File logFile = SD.open(logFileName, FILE_WRITE); // Open the log file

  if (logFile)
  { // Print longitude, latitude, altitude (in feet), speed (in mph), course
    // in (degrees), date, time, and number of satellites.
    logFile.print(tinyGPS.location.lng(), 6);
    logFile.print(',');
    logFile.print(tinyGPS.location.lat(), 6);
    logFile.print(',');
    logFile.print(tinyGPS.altitude.feet(), 1);
    logFile.print(',');
    logFile.print(tinyGPS.speed.mph(), 1);
    logFile.print(',');
    logFile.print(tinyGPS.course.deg(), 1);
    logFile.print(',');
    logFile.print(tinyGPS.date.value());
    logFile.print(',');
    logFile.print(tinyGPS.time.value());
    logFile.print(',');
    logFile.print(tinyGPS.satellites.value());
    logFile.println();
    logFile.close();

    return 1; // Return success
  }

  return 0; // If we failed to open the file, return fail
}

// printHeader() - prints our eight column names to the top of our log file
void printHeader()
{
  File logFile = SD.open(logFileName, FILE_WRITE); // Open the log file

  if (logFile) // If the log file opened, print our column names to the file
  {
    int i = 0;
    for (; i < LOG_COLUMN_COUNT; i++)
    {
      logFile.print(log_col_names[i]);
      if (i < LOG_COLUMN_COUNT - 1) // If it's anything but the last column
        logFile.print(','); // print a comma
      else // If it's the last column
        logFile.println(); // print a new line
    }
    logFile.close(); // close the file
  }
}

// updateFileName() - Looks through the log files already present on a card,
// and creates a new file with an incremented file index.
void updateFileName()
{
  int i = 0;
  for (; i < MAX_LOG_FILES; i++)
  {
    memset(logFileName, 0, strlen(logFileName)); // Clear logFileName string
    // Set logFileName to "gpslogXX.csv":
    sprintf(logFileName, "%s%d.%s", LOG_FILE_PREFIX, i, LOG_FILE_SUFFIX);
    if (!SD.exists(logFileName)) // If a file doesn't exist
    {
      break; // Break out of this loop. We found our index
    }
    else // Otherwise:
    {
      SerialMonitor.print(logFileName);
      SerialMonitor.println(" exists"); // Print a debug statement
    }
  }
  SerialMonitor.print("File name: ");
  SerialMonitor.println(logFileName); // Debug print the file name
}

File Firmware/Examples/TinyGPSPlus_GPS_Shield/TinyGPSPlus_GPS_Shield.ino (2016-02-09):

/******************************************************************************
  TinyGPSPlus_GPS_Shield.ino
  TinyGPS++ Library Example for the SparkFun GPS Logger Shield
  By Jim Lindblom @ SparkFun Electronics
  February 9, 2016
  https://github.com/sparkfun/GPS_Shield

  This example uses SoftwareSerial to communicate with the GPS module on
  pins 8 and 9. It uses the TinyGPS++ library to parse the NMEA strings sent
  by the GPS module, and prints interesting GPS information to the serial
  monitor.

  After uploading the code, open your serial monitor, set it to 9600 baud, and
  watch for latitude, longitude, altitude, course, speed, date, time, and the
  number of visible satellites.

  Resources:
  TinyGPS++ Library  - https://github.com/mikalhart/TinyGPSPlus/releases
  SoftwareSerial Library

  Development/hardware environment specifics:
  Arduino IDE 1.6.7
  GPS Logger Shield v2.0 - Make sure the UART switch is set to SW-UART
  Arduino Uno, RedBoard, Pro, Mega, etc.
******************************************************************************/

#include <TinyGPS++.h> // Include the TinyGPS++ library
TinyGPSPlus tinyGPS; // Create a TinyGPSPlus object

#define GPS_BAUD 9600 // GPS module baud rate. GP3906 defaults to 9600.

// If you're using an Arduino Uno, Mega, RedBoard, or any board that uses the
// 0/1 UART for programming/Serial monitor-ing, use SoftwareSerial:
#include <SoftwareSerial.h>
#define ARDUINO_GPS_RX 9 // GPS TX, Arduino RX pin
#define ARDUINO_GPS_TX 8 // GPS RX, Arduino TX pin
SoftwareSerial ssGPS(ARDUINO_GPS_TX, ARDUINO_GPS_RX); // Create a SoftwareSerial

// Set gpsPort to either ssGPS if using SoftwareSerial or Serial1 if using an
// Arduino with a dedicated hardware serial port
#define gpsPort ssGPS  // Alternatively, use Serial1 on the Leonardo

// Define the serial monitor port. On the Uno, Mega, and Leonardo this is 'Serial'
//  on other boards this may be 'SerialUSB'
#define SerialMonitor Serial

void setup()
{
  SerialMonitor.begin(9600);
  gpsPort.begin(GPS_BAUD);
}

void loop()
{
  // print position, altitude, speed, time/date, and satellites:
  printGPSInfo();
  
  // "Smart delay" looks for GPS data while the Arduino's not doing anything else
  smartDelay(1000); 
}

void printGPSInfo()
{
  // Print latitude, longitude, altitude in feet, course, speed, date, time,
  // and the number of visible satellites.
  SerialMonitor.print("Lat: "); SerialMonitor.println(tinyGPS.location.lat(), 6);
  SerialMonitor.print("Long: "); SerialMonitor.println(tinyGPS.location.lng(), 6);
  SerialMonitor.print("Alt: "); SerialMonitor.println(tinyGPS.altitude.feet());
  SerialMonitor.print("Course: "); SerialMonitor.println(tinyGPS.course.deg());
  SerialMonitor.print("Speed: "); SerialMonitor.println(tinyGPS.speed.mph());
  SerialMonitor.print("Date: "); printDate();
  SerialMonitor.print("Time: "); printTime();
  SerialMonitor.print("Sats: "); SerialMonitor.println(tinyGPS.satellites.value());
  SerialMonitor.println();
}

// This custom version of delay() ensures that the tinyGPS object
// is being "fed". From the TinyGPS++ examples.
static void smartDelay(unsigned long ms)
{
  unsigned long start = millis();
  do
  {
    // If data has come in from the GPS module
    while (gpsPort.available())
      tinyGPS.encode(gpsPort.read()); // Send it to the encode function
	// tinyGPS.encode(char) continues to "load" the tinGPS object with new
	// data coming in from the GPS module. As full NMEA strings begin to come in
	// the tinyGPS library will be able to start parsing them for pertinent info
  } while (millis() - start < ms);
}

// printDate() formats the date into dd/mm/yy.
void printDate()
{
  SerialMonitor.print(tinyGPS.date.day());
  SerialMonitor.print("/");
  SerialMonitor.print(tinyGPS.date.month());
  SerialMonitor.print("/");
  SerialMonitor.println(tinyGPS.date.year());
}

// printTime() formats the time into "hh:mm:ss", and prints leading 0's
// where they're called for.
void printTime()
{
  SerialMonitor.print(tinyGPS.time.hour());
  SerialMonitor.print(":");
  if (tinyGPS.time.minute() < 10) SerialMonitor.print('0');
  SerialMonitor.print(tinyGPS.time.minute());
  SerialMonitor.print(":");
  if (tinyGPS.time.second() < 10) SerialMonitor.print('0');
  SerialMonitor.println(tinyGPS.time.second());
}

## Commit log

2015-02-03 Initial commit with brd/sch
    [GPS_Shield.brd, GPS_Shield.sch]
2015-10-07 Initial commit of v2.0
    - Added micro SD socket
    - Switched GPS to new PCB-mountable version
    - Updated shield to R3 footprint
    [GPS_Shield.brd, GPS_Shield.sch]
2015-10-12 Adding measures, cleaning up schematic
    [GPS_Shield.brd, GPS_Shield.sch]
2015-10-12 Changing GP-735 module's VCC to 3.3V
    [GPS_Shield.brd, GPS_Shield.sch]
2015-10-12 Moving GP-735 connector to bottom side, marking DNP
    [GPS_Shield.brd, GPS_Shield.sch]
2015-10-14 Upping isolate to 0.01", adding some GND vias.
    [GPS_Shield.brd]
2015-10-14 Clarifying GPS's pin 1 indicator.
    [GPS_Shield.brd, GPS_Shield.sch]
2015-11-16 Adding VBATT-to-3.3V jumper, breaking out VBATT.
    [GPS_Shield.brd, GPS_Shield.sch]
2015-11-16 Changing DRU to SparkFun-2-Layer-Tight, slightly moving traces to accomodate.
    [GPS_Shield.brd]
2015-11-23 Schematic and trace cleanup.
    [GPS_Shield.brd, GPS_Shield.sch]
2015-11-24 Removing GP-735 fp. Default 3.3/VBat jumper closed.
    [GPS_Shield.brd, GPS_Shield.sch]
2015-11-24 Schematic cleanup
    [GPS_Shield.brd, GPS_Shield.sch]
2015-11-24 Silkscreen adjustments.
    [GPS_Shield.brd]
2015-11-24 Upping paste on GPS module pins by 50%
    [GPS_Shield.brd, GPS_Shield.sch]
2015-11-24 Default SJ11 to open.
    [GPS_Shield.brd, GPS_Shield.sch]
2015-11-24 Adding note about battery required.
    [GPS_Shield.brd]
2015-11-30 Updating 12mm battery PROD_ID
    [GPS_Shield.brd, GPS_Shield.sch]
2015-12-02 created panel v20
    [GPS_Shield_Panel_v20.brd]

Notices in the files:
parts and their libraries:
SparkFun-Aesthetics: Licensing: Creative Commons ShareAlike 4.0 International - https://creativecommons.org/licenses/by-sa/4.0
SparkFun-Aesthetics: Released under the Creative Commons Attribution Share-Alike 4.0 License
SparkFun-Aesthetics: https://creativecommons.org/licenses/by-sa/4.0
